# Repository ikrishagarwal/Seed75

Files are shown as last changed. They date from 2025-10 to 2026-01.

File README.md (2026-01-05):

# Seed75

A completely hand made 75% mechanical keyboard from PCB to case, even the firmware.

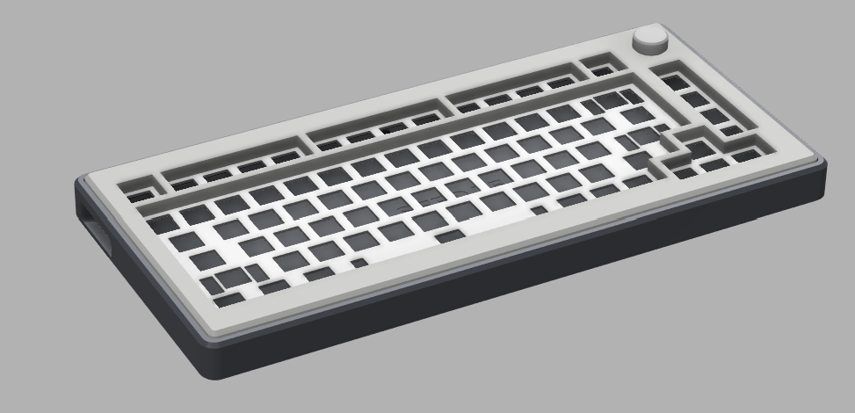
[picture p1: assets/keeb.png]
Seed75


## Features

- 75% Layout
- Hot Swappable Sockets
- Sleep Design
- Customizable Push Knob
- USB C Port
- Detachable Angle Elevation
- Sandwich Mount
- Wrist Rest

## Images

### PCB Schematics

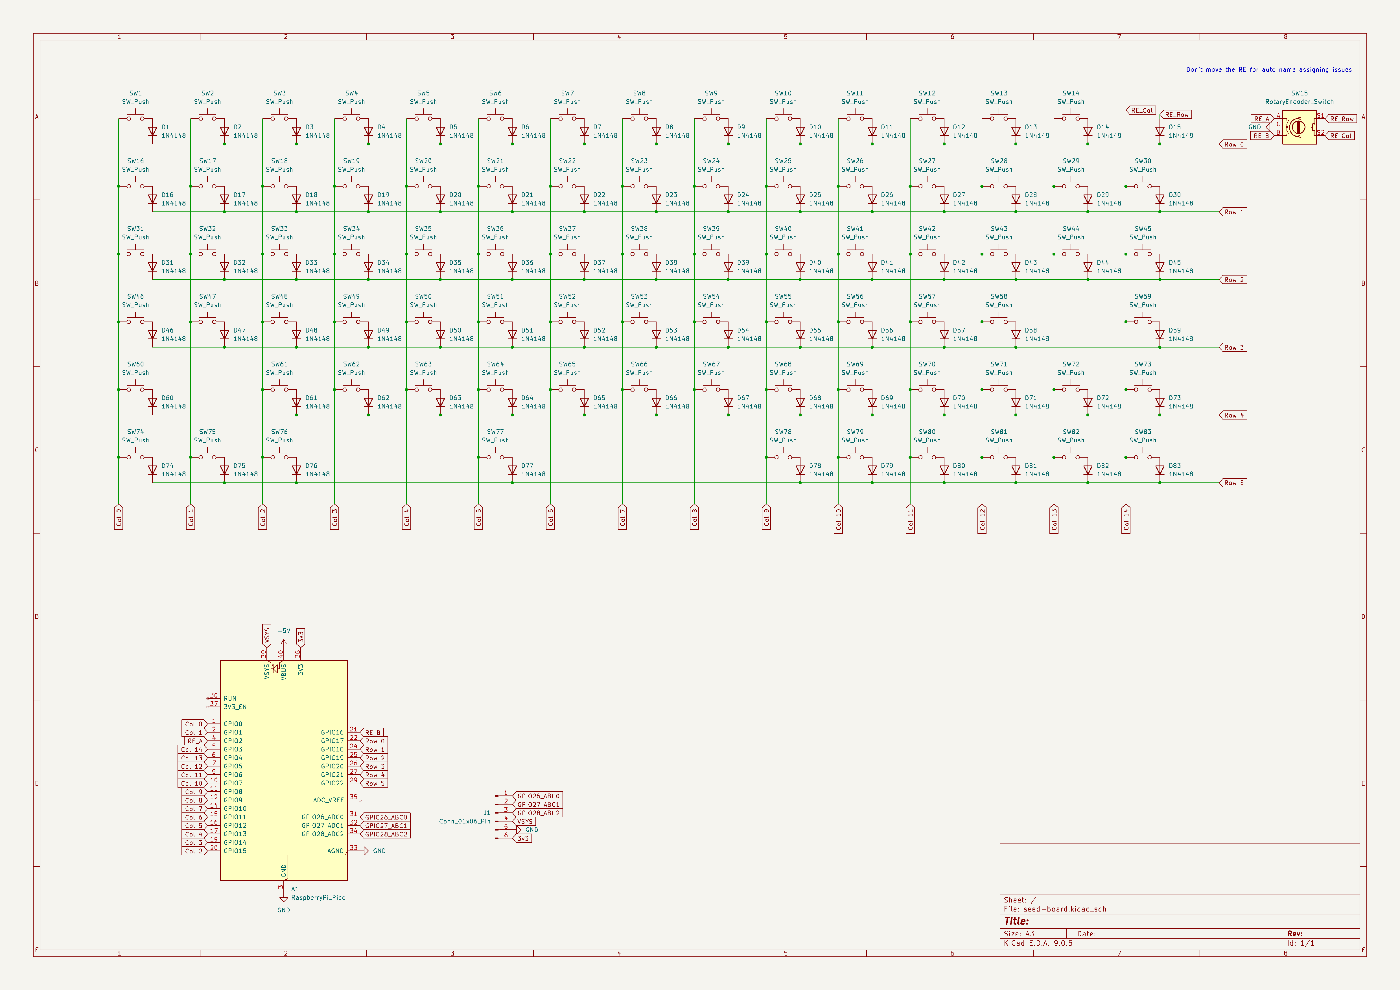
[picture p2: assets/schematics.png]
PCB Schematics


### PCB

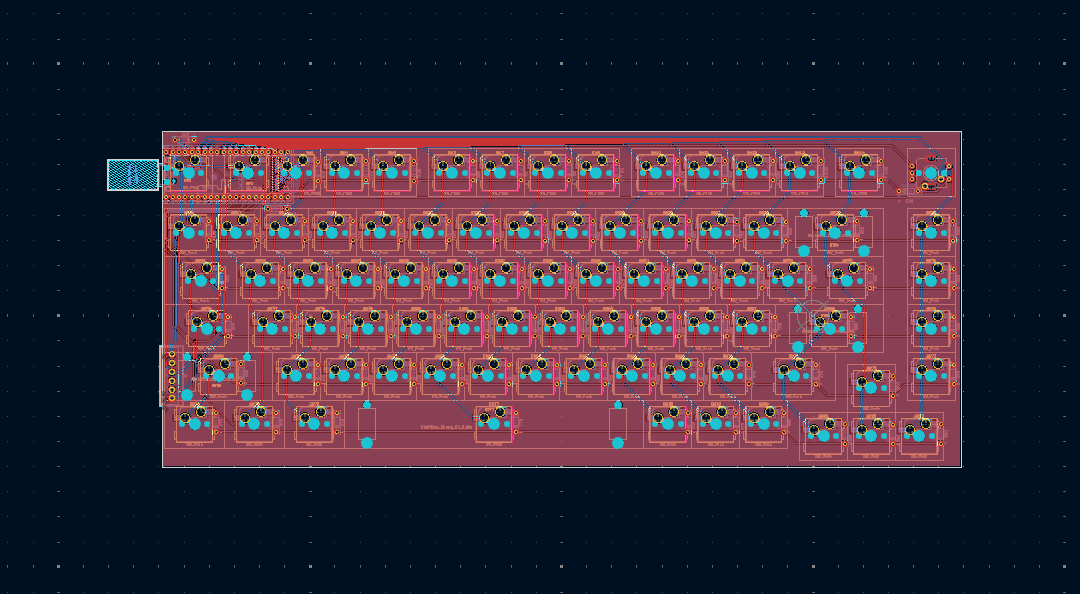
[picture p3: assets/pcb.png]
PCB


### PCB Front Layer

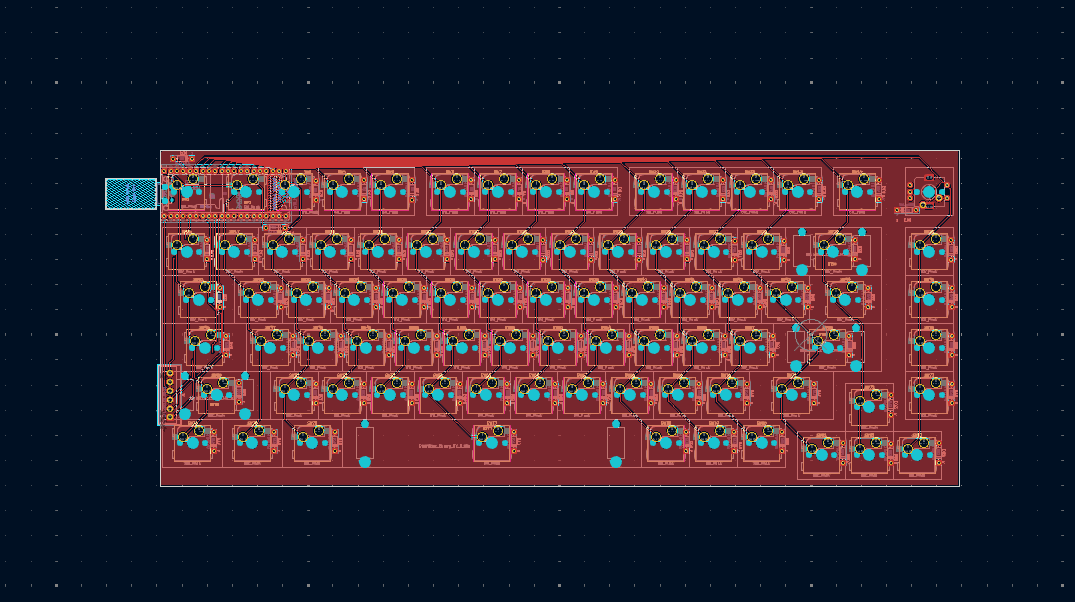
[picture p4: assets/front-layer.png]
PCB Front Layer


### PCB Back Layer

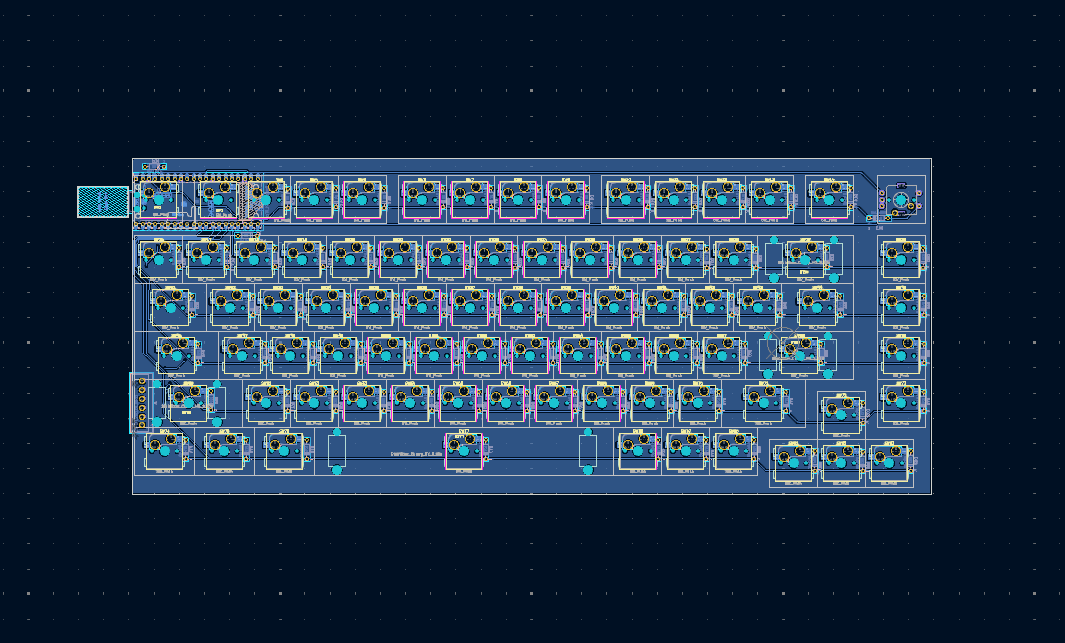
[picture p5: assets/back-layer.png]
PCB Back Layer


### PCB Rendered Front

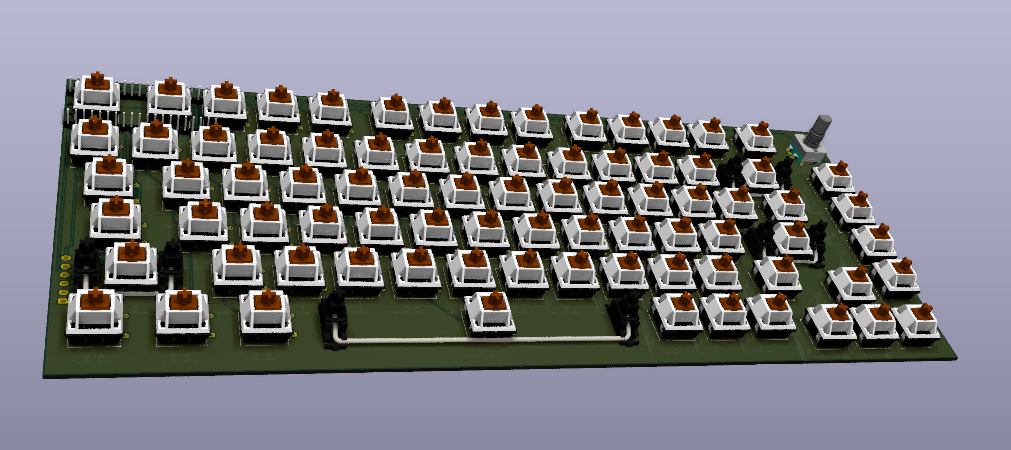
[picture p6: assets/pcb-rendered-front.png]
PCB Top


### PCB Rendered Back

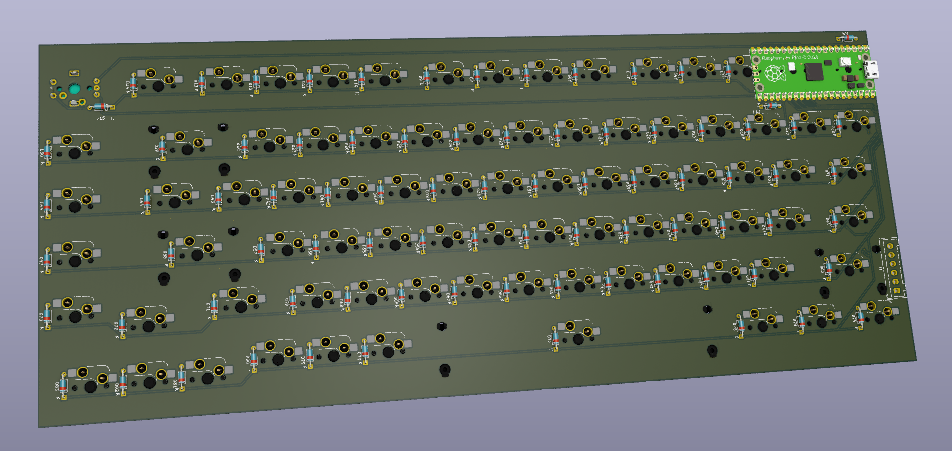
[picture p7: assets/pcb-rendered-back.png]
PCB Back


### Complete Case

Case

### Bottom Case

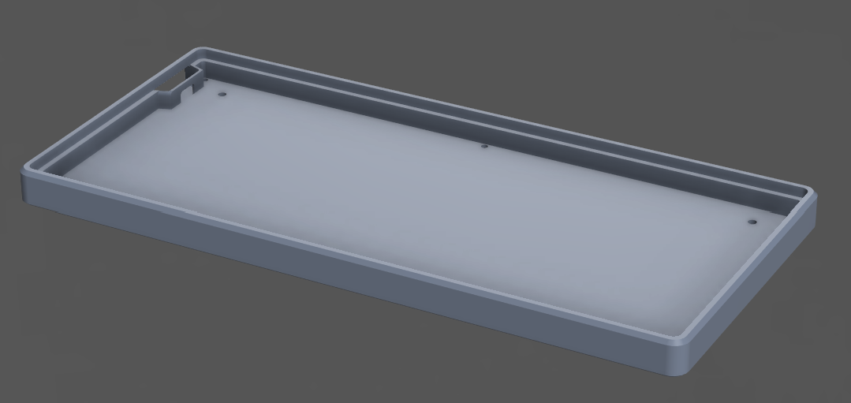
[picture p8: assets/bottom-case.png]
Bottom Case


### Top Case

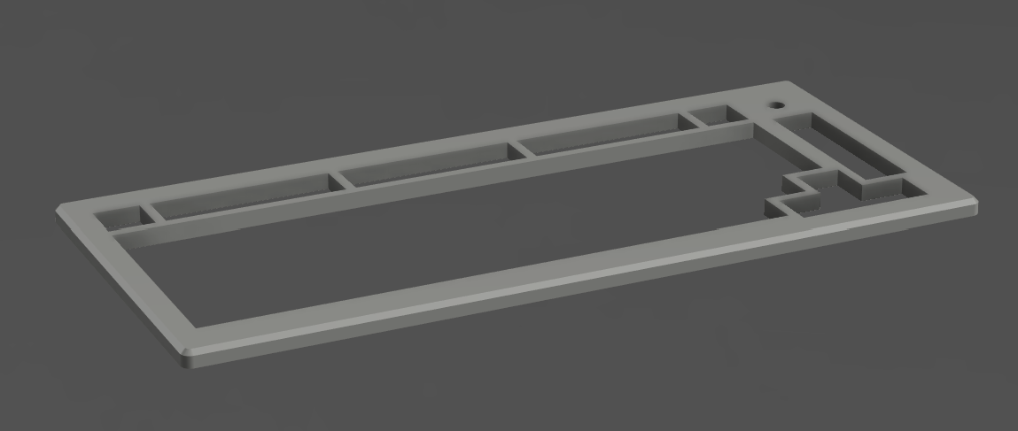
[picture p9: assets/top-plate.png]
Top Case


### Plate

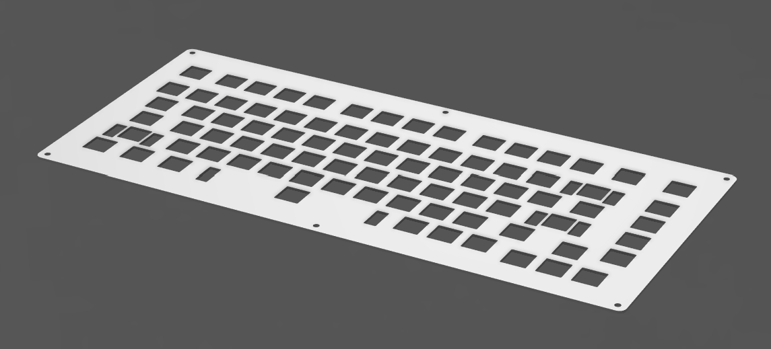
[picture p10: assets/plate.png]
Plate


### Elevator

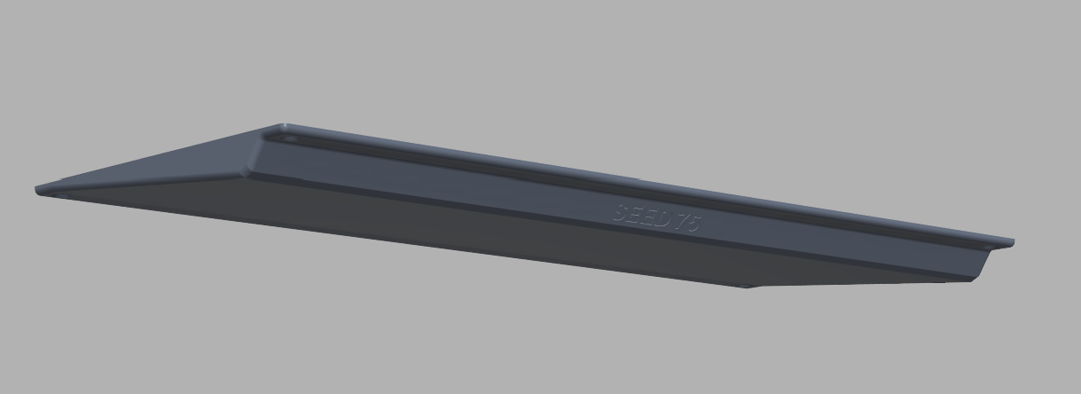
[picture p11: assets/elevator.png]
Elevator


### Wrist Rest

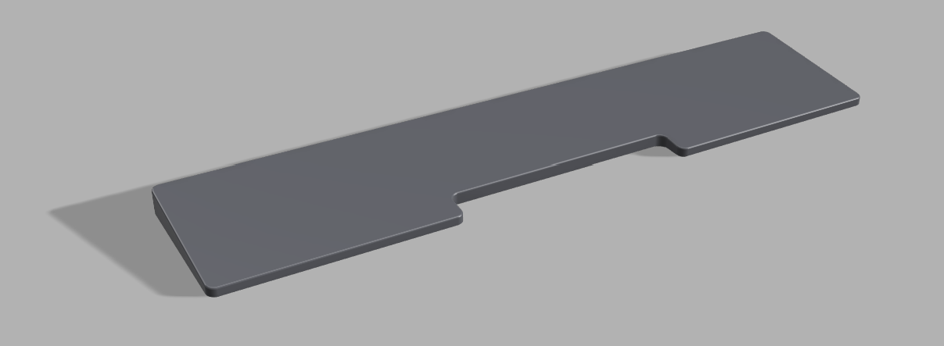
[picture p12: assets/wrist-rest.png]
Wrist Rest


### Knob

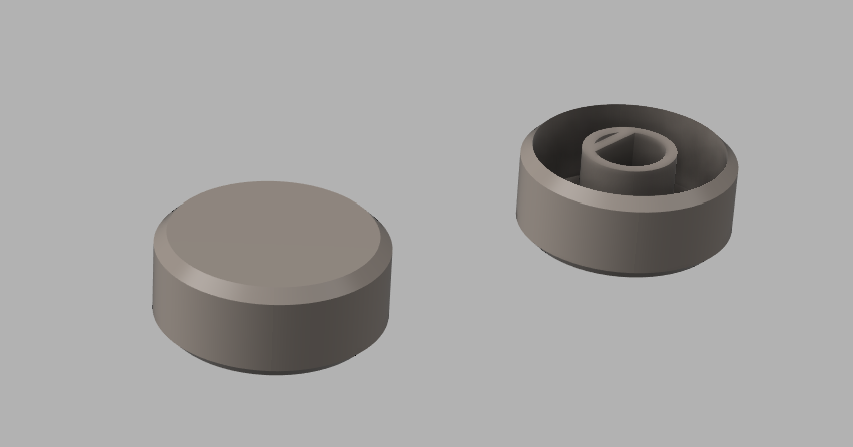
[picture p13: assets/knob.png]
Knob


### BOM

| Item | Quantity | Cost (USD)\* | Purchase Link |
| --- | --- | --- | --- |
| 1N4148 Diodes | 90 Pack  | 1.52 | https://stackskb.com/store/1n4148-through-hole-diode/ |
| Akko Bittersweet Switch | 90 Pack  | 33.40 | https://stackskb.com/store/akko-bittersweet-switch-pack-of-45/ |
| EC11 Rotary Encoder | 1 | 0.43 | https://www.flyrobo.in/ec11-rotary-encoder-half-shaft-handle-potentiometer-15mm |
| Orpheus Pico | 1 | | Hack Club |
| Gateron Hotswap Sockets | 90 Pack  | 10.00 | https://stackskb.com/store/gateron-hotswap-sockets/ |
| Durock v2 Stabilizers Set | 1 | 17.98 | https://stackskb.com/store/durock-clear-screw-in-stabilizers-v2/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 |
| Keycap Set | 1 | 22.21 | https://curiositycaps.in/products/camp-picnic-xvx-p-profile-dye-sub-doubleshot-combination-keycap |
| M3x20 Hex CSK Screws | 6x2 | 0.20 | https://omrook.com/ss-allen-csk-m3-x-20mm-dia-3mm-length-20mm-stainless-steel-ss202-allen-socket-countersunk-screws/ |
| M3x6 Hex CSK Screws | 4x2 | 0.05 | https://omrook.com/ss-allen-csk-m3-x-6mm-dia-3mm-length-6mm-stainless-steel-ss202-allen-socket-countersunk-screws/ |
| M3 X 3mm Brass Threaded Inserts | 10x2 | 0.83 | https://omrook.com/m3-x-4-brass-threaded-inserts-nut-50pc/ |
| Bottom Case, Top Case, Plate, Knob, Elevator, Wrist Rest | 1 | | (3D Printed) |
| PCB | 1 | 56.87 | https://www.pcbpower.com/ |

Cost is as of 01/01/2026

## Software Used

- KiCAD
- Fusion 360

## Author

[Krish](https://github.com/ikrishagarwal)

## License

This project is licensed under the [AGPL-3.0 License](LICENSE).

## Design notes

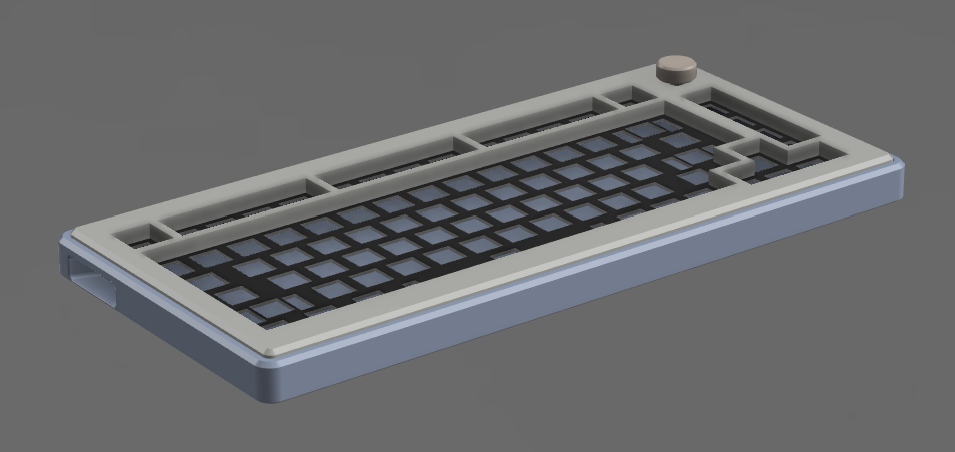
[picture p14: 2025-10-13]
assets/case.png

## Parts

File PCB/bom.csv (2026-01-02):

Designator | Footprint | Quantity | Value | LCSC Part #
A1 | Raspberry_Pi_Pico | 1 | RaspberryPi_Pico
D1, D10, D11, D12, D13, D14, D15, D16, D17, D18, D19, D2, D20, D21, D22, D23, D24, D25, D26, D27, D28, D29, D3, D30, D31, D32, D33, D34, D35, D36, D37, D38, D39, D4, D40, D41, D42, D43, D44, D45, D46, D47, D48, D49, D5, D50, D51, D52, D53, D54, D55, D56, D57, D58, D59, D6, D60, D61, D62, D63, D64, D65, D66, D67, D68, D69, D7, D70, D71, D72, D73, D74, D75, D76, D77, D78, D79, D8, D80, D81, D82, D83, D9 | D_DO-35_SOD27_P7.62mm_Horizontal | 83 | 1N4148
J1 | Wago_734-136_1x06_P3.50mm_Vertical | 1 | Conn_01x06_Pin
SW1, SW10, SW11, SW12, SW13, SW14, SW16, SW17, SW18, SW19, SW2, SW20, SW21, SW22, SW23, SW24, SW25, SW26, SW27, SW28, SW3, SW30, SW32, SW33, SW34, SW35, SW36, SW37, SW38, SW39, SW4, SW40, SW41, SW42, SW43, SW45, SW47, SW48, SW49, SW5, SW50, SW51, SW52, SW53, SW54, SW55, SW56, SW57, SW59, SW6, SW61, SW62, SW63, SW64, SW65, SW66, SW67, SW68, SW69, SW7, SW70, SW72, SW73, SW78, SW79, SW8, SW80, SW81, SW82, SW83, SW9 | SW_Hotswap_Kailh_MX_Plated_1.00u_With_Switch | 71 | SW_Push
SW15 | Encoder_EC11_MX_Combo | 1 | RotaryEncoder_Switch
SW29 | SW_Hotswap_Kailh_MX_Plated_2.00u_With_Switch | 1 | SW_Push
SW31, SW44 | SW_Hotswap_Kailh_MX_Plated_1.50u_With_Switch | 2 | SW_Push
SW46, SW71 | SW_Hotswap_Kailh_MX_Plated_1.75u_With_Switch | 2 | SW_Push
SW58, SW60 | SW_Hotswap_Kailh_MX_Plated_2.25u_With_Switch | 2 | SW_Push
SW74, SW75, SW76 | SW_Hotswap_Kailh_MX_Plated_1.25u_With_Switch | 3 | SW_Push
SW77 | SW_Hotswap_Kailh_MX_Plated_6.25u_With_Switch | 1 | SW_Push

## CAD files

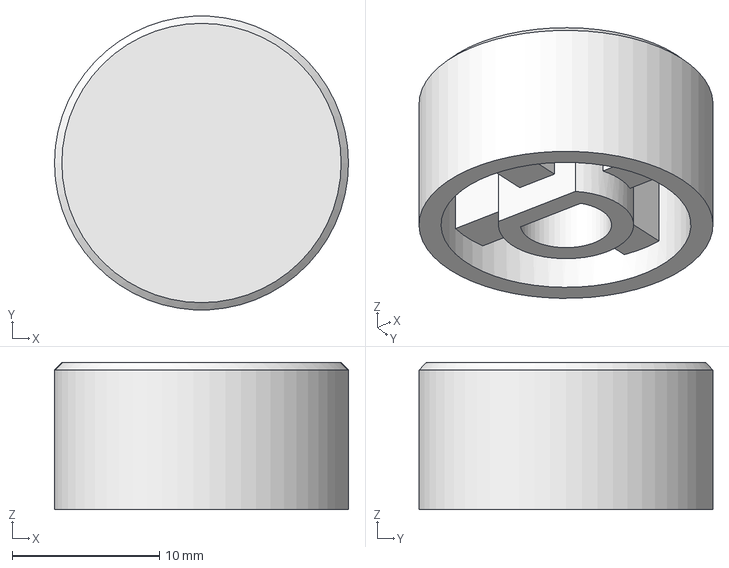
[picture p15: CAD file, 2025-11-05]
CAD/Knob.step
20.0 x 20.0 x 10.0 mm

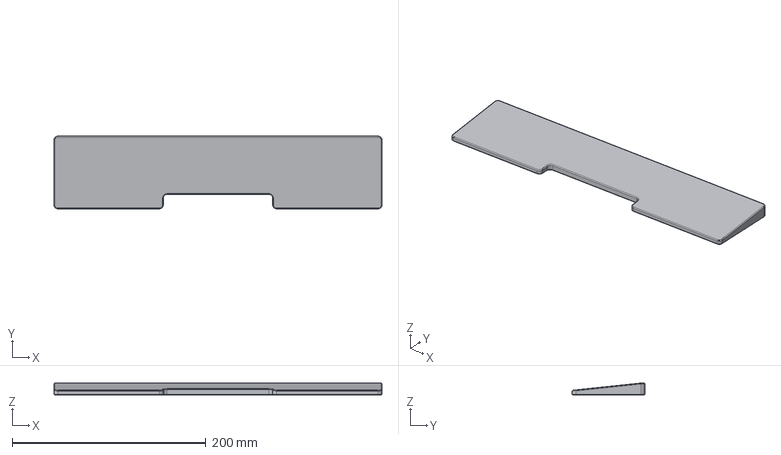
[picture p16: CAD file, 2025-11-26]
Production/WristRest.step
338.8 x 75.0 x 12.9 mm

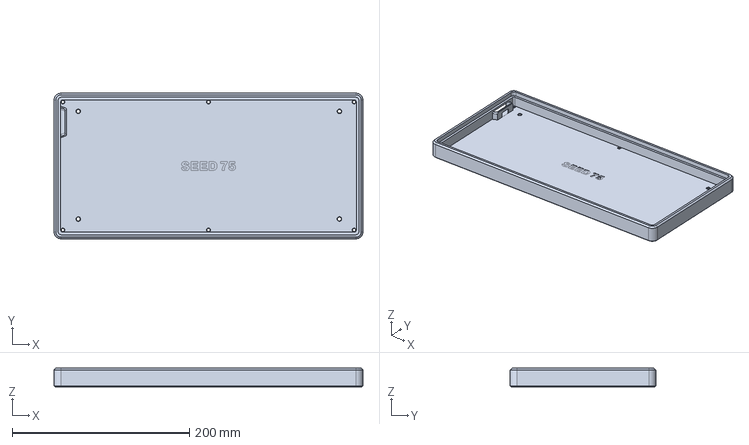
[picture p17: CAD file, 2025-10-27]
CAD/Bottom Case.step
348.8 x 164.5 x 21.0 mm

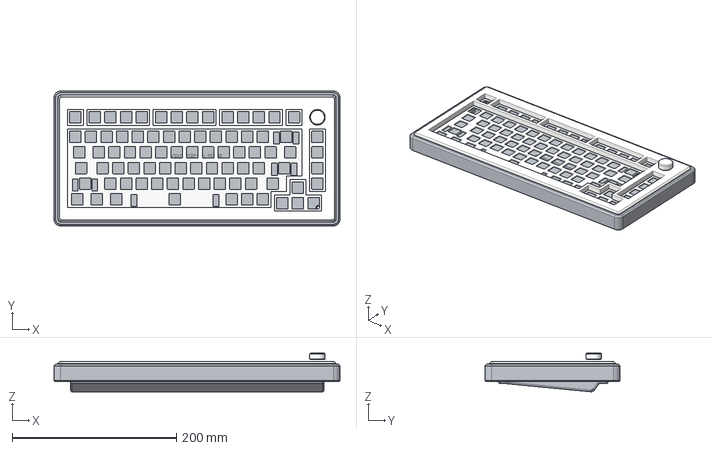
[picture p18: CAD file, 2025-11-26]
Production/Seed75.step
348.8 x 164.5 x 47.3 mm

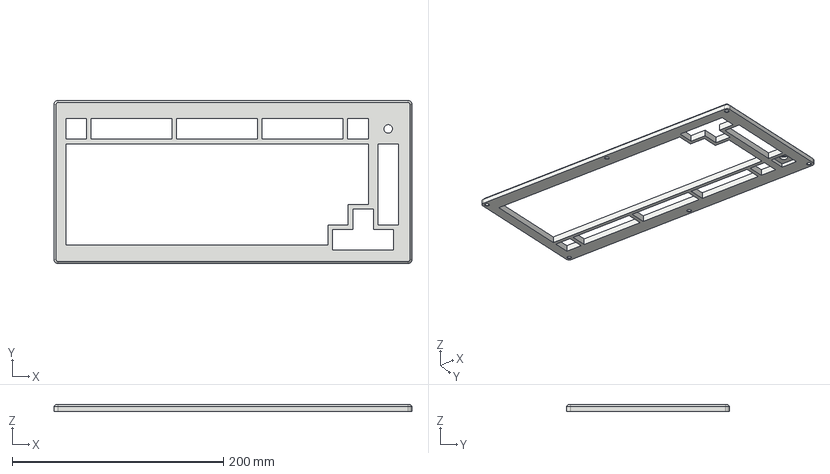
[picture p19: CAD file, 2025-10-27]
CAD/Top Case.step
338.8 x 154.5 x 7.00 mm

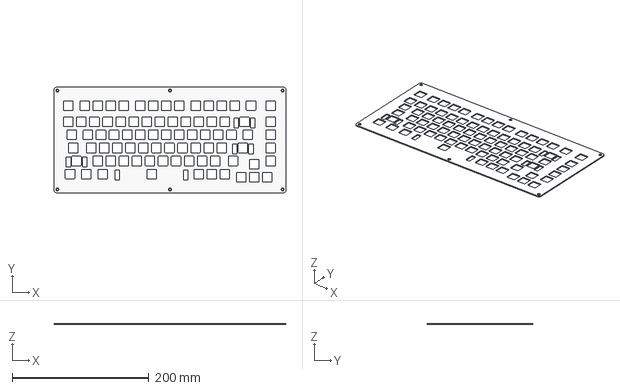
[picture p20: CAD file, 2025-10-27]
CAD/Plate.step
338.8 x 154.5 x 1.50 mm

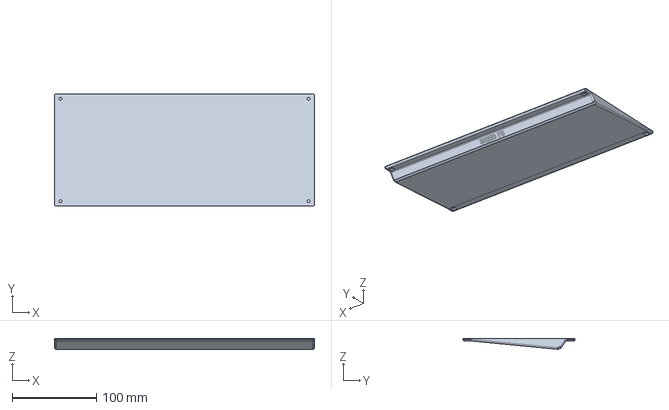
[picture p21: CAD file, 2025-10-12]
CAD/Stand.step
308.8 x 133.5 x 12.8 mm

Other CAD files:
CAD/Wrist Rest.step
CAD/Bottom Case.stl
CAD/Knob.stl
CAD/Plate.stl
CAD/Stand.stl
CAD/Top Case.stl
CAD/Wrist Rest.stl

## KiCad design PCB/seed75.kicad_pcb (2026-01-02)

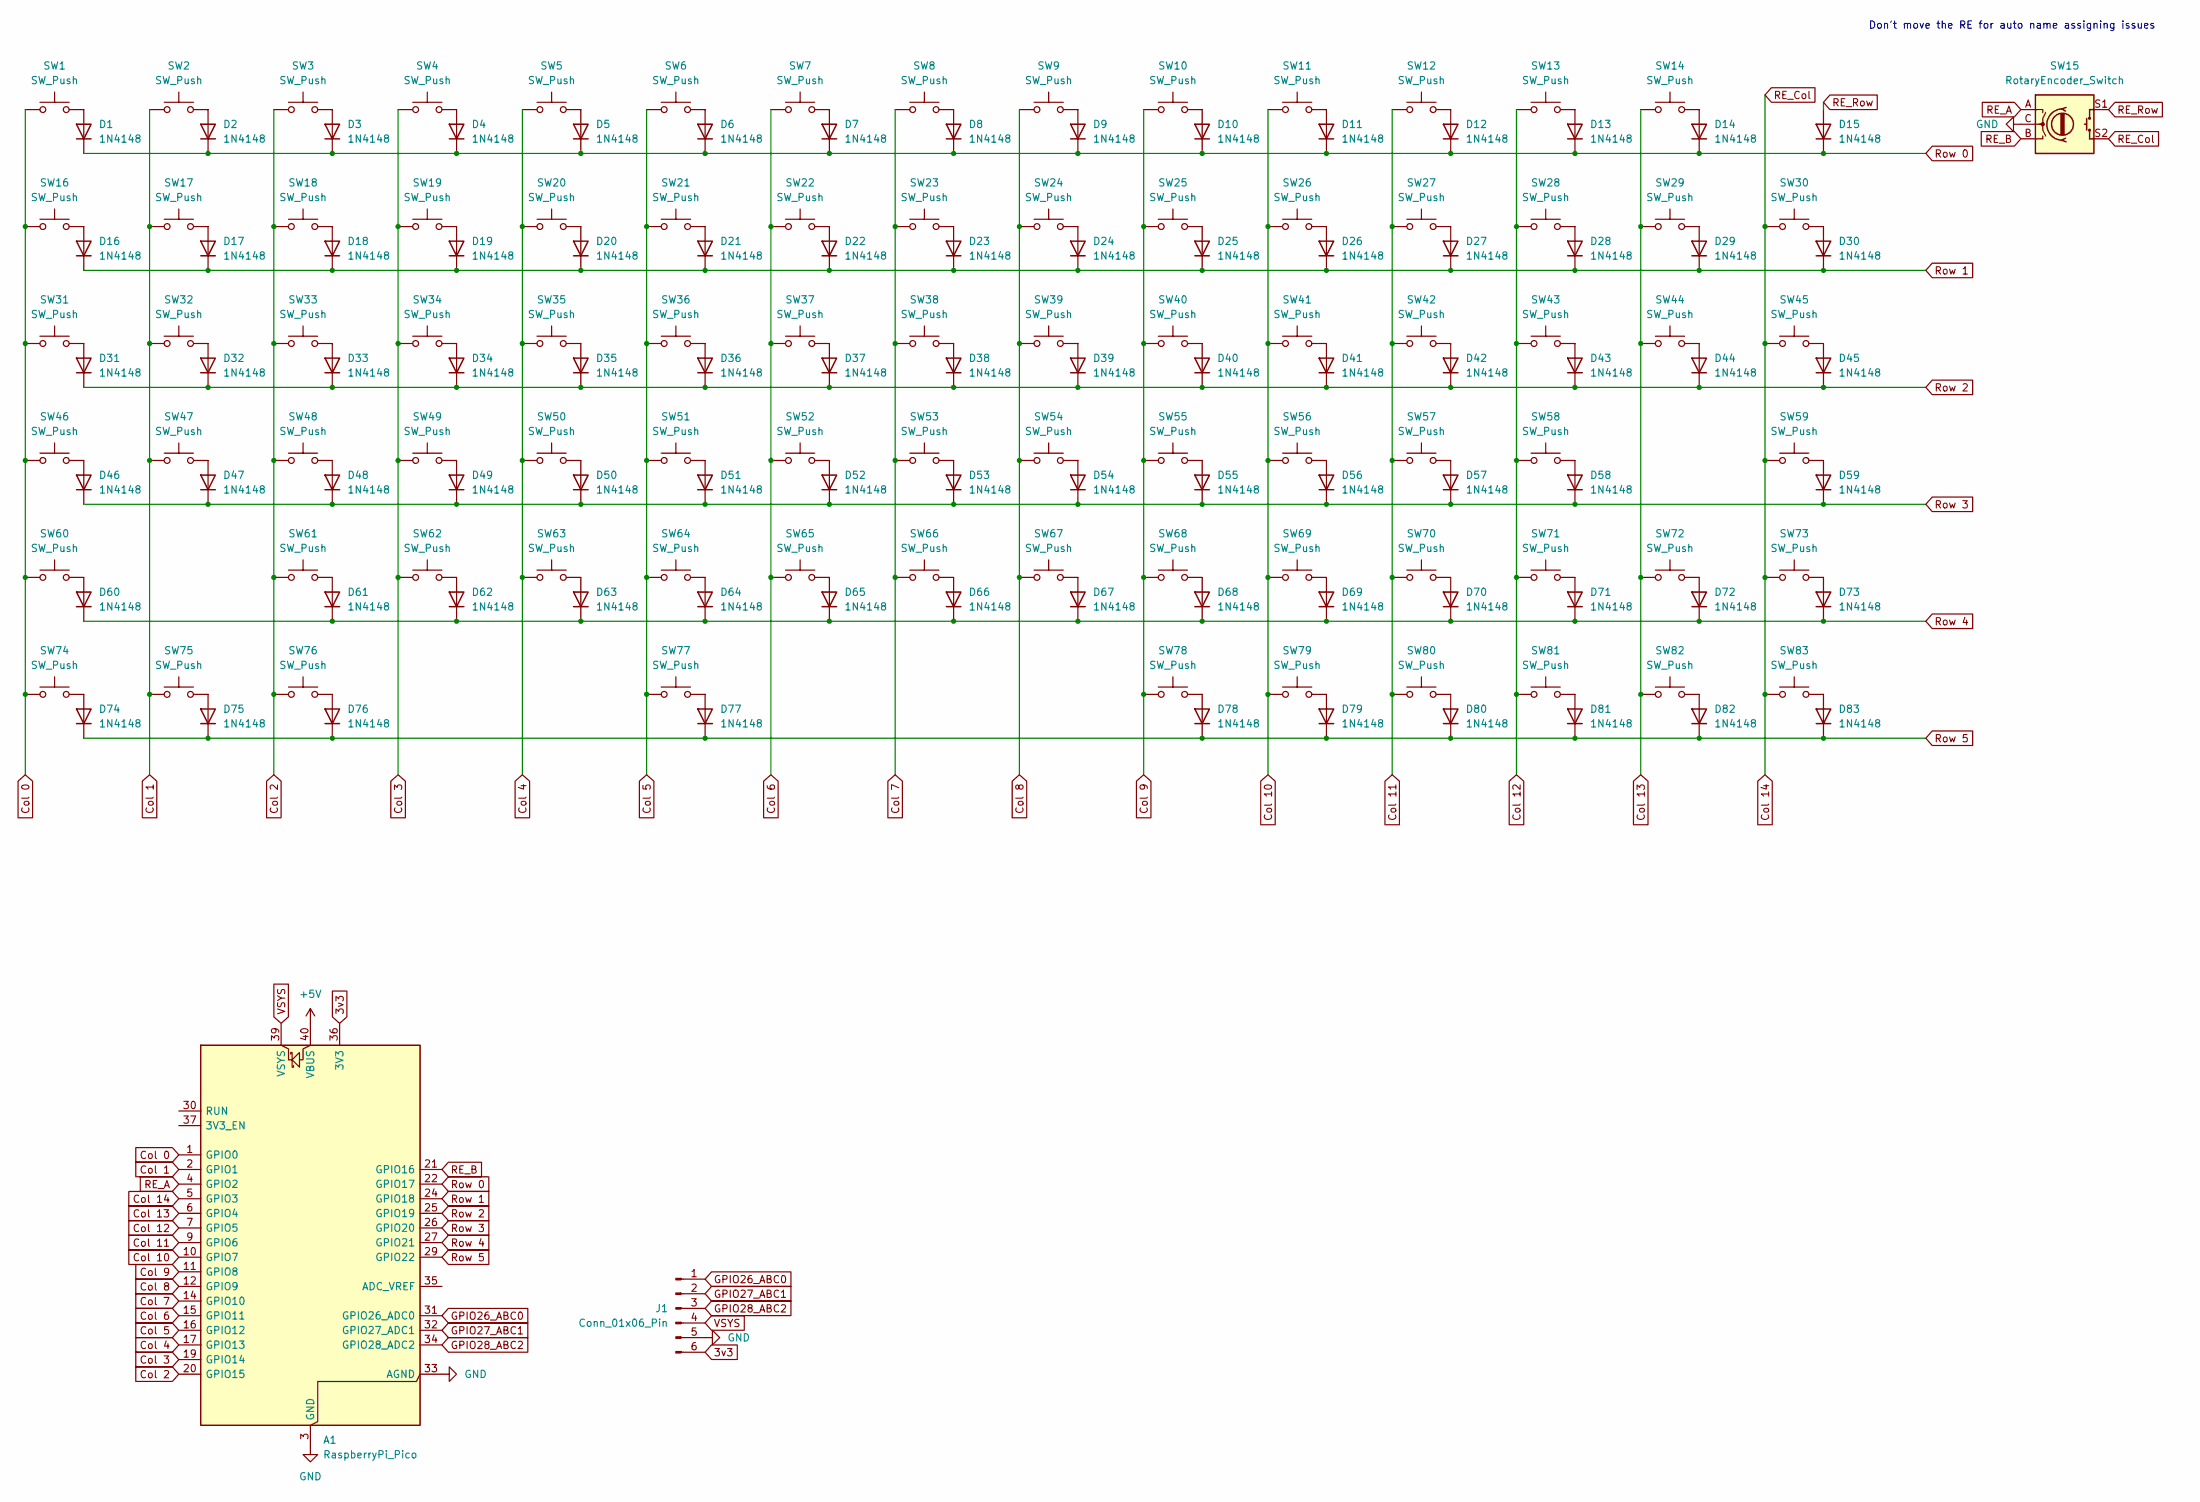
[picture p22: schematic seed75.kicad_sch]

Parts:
A1: RaspberryPi_Pico; Raspberry_Pi_Pico
D1, D2, D3, D4, D5, D6, D7, D8, D9, D10, D11, D12, D13, D14, D15, D16, D17, D18, D19, D20, D21, D22, D23, D24, D25, D26, D27, D28, D29, D30, D31, D32, D33, D34, D35, D36, D37, D38, D39, D40, D41, D42, D43, D44, D45, D46, D47, D48, D49, D50, D51, D52, D53, D54, D55, D56, D57, D58, D59, D60, D61, D62, D63, D64, D65, D66, D67, D68, D69, D70, D71, D72, D73, D74, D75, D76, D77, D78, D79, D80, D81, D82, D83: 1N4148; D_DO-35_SOD27_P7.62mm_Horizontal
J1: Conn_01x06_Pin; Wago_734-136_1x06_P3.50mm_Vertical
SW1, SW2, SW3, SW4, SW5, SW6, SW7, SW8, SW9, SW10, SW11, SW12, SW13, SW14, SW16, SW17, SW18, SW19, SW20, SW21, SW22, SW23, SW24, SW25, SW26, SW27, SW28, SW30, SW32, SW33, SW34, SW35, SW36, SW37, SW38, SW39, SW40, SW41, SW42, SW43, SW45, SW47, SW48, SW49, SW50, SW51, SW52, SW53, SW54, SW55, SW56, SW57, SW59, SW61, SW62, SW63, SW64, SW65, SW66, SW67, SW68, SW69, SW70, SW72, SW73, SW78, SW79, SW80, SW81, SW82, SW83: SW_Push; SW_Hotswap_Kailh_MX_Plated_1.00u_With_Switch
SW15: RotaryEncoder_Switch; Encoder_EC11_MX_Combo
SW29: SW_Push; SW_Hotswap_Kailh_MX_Plated_2.00u_With_Switch
SW31, SW44: SW_Push; SW_Hotswap_Kailh_MX_Plated_1.50u_With_Switch
SW46, SW71: SW_Push; SW_Hotswap_Kailh_MX_Plated_1.75u_With_Switch
SW58, SW60: SW_Push; SW_Hotswap_Kailh_MX_Plated_2.25u_With_Switch
SW74, SW75, SW76: SW_Push; SW_Hotswap_Kailh_MX_Plated_1.25u_With_Switch
SW77: SW_Push; SW_Hotswap_Kailh_MX_Plated_6.25u_With_Switch

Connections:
3v3: A1.36 (3V3), J1.6
+5V: A1.40 (VBUS)
Col 0: A1.1 (GPIO0), SW1.1, SW16.1, SW31.1, SW46.1, SW60.1, SW74.1
Col 1: A1.2 (GPIO1), SW2.1, SW17.1, SW32.1, SW47.1, SW75.1
Col 2: A1.20 (GPIO15), SW3.1, SW18.1, SW33.1, SW48.1, SW61.1, SW76.1
Col 3: A1.19 (GPIO14), SW4.1, SW19.1, SW34.1, SW49.1, SW62.1
Col 4: A1.17 (GPIO13), SW5.1, SW20.1, SW35.1, SW50.1, SW63.1
Col 5: A1.16 (GPIO12), SW6.1, SW21.1, SW36.1, SW51.1, SW64.1, SW77.1
Col 6: A1.15 (GPIO11), SW7.1, SW22.1, SW37.1, SW52.1, SW65.1
Col 7: A1.14 (GPIO10), SW8.1, SW23.1, SW38.1, SW53.1, SW66.1
Col 8: A1.12 (GPIO9), SW9.1, SW24.1, SW39.1, SW54.1, SW67.1
Col 9: A1.11 (GPIO8), SW10.1, SW25.1, SW40.1, SW55.1, SW68.1, SW78.1
Col 10: A1.10 (GPIO7), SW11.1, SW26.1, SW41.1, SW56.1, SW69.1, SW79.1
Col 11: A1.9 (GPIO6), SW12.1, SW27.1, SW42.1, SW57.1, SW70.1, SW80.1
Col 12: A1.7 (GPIO5), SW13.1, SW28.1, SW43.1, SW58.1, SW71.1, SW81.1
Col 13: A1.6 (GPIO4), SW14.1, SW29.1, SW44.1, SW72.1, SW82.1
Col 14: A1.5 (GPIO3), SW15.S2, SW30.1, SW45.1, SW59.1, SW73.1, SW83.1
GND: A1.3 (GND), A1.8 (GND), A1.13 (GND), A1.18 (GND), A1.23 (GND), A1.28 (GND), A1.33 (AGND), A1.38 (GND), J1.5, SW15.C
GPIO26_ABC0: A1.31 (GPIO26_ADC0), J1.1
GPIO27_ABC1: A1.32 (GPIO27_ADC1), J1.2
GPIO28_ABC2: A1.34 (GPIO28_ADC2), J1.3
unnamed: D1.2 (A), SW1.2
unnamed: D2.2 (A), SW2.2
unnamed: D3.2 (A), SW3.2
unnamed: D4.2 (A), SW4.2
unnamed: D5.2 (A), SW5.2
unnamed: D6.2 (A), SW6.2
unnamed: D7.2 (A), SW7.2
unnamed: D8.2 (A), SW8.2
unnamed: D9.2 (A), SW9.2
unnamed: D10.2 (A), SW10.2
unnamed: D11.2 (A), SW11.2
unnamed: D12.2 (A), SW12.2
unnamed: D13.2 (A), SW13.2
unnamed: D14.2 (A), SW14.2
unnamed: D16.2 (A), SW16.2
unnamed: D17.2 (A), SW17.2
unnamed: D18.2 (A), SW18.2
unnamed: D19.2 (A), SW19.2
unnamed: D20.2 (A), SW20.2
unnamed: D21.2 (A), SW21.2
unnamed: D22.2 (A), SW22.2
unnamed: D23.2 (A), SW23.2
unnamed: D24.2 (A), SW24.2
unnamed: D25.2 (A), SW25.2
unnamed: D26.2 (A), SW26.2
unnamed: D27.2 (A), SW27.2
unnamed: D28.2 (A), SW28.2
unnamed: D29.2 (A), SW29.2
unnamed: D30.2 (A), SW30.2
unnamed: D31.2 (A), SW31.2
unnamed: D32.2 (A), SW32.2
unnamed: D33.2 (A), SW33.2
unnamed: D34.2 (A), SW34.2
unnamed: D35.2 (A), SW35.2
unnamed: D36.2 (A), SW36.2
unnamed: D37.2 (A), SW37.2
unnamed: D38.2 (A), SW38.2
unnamed: D39.2 (A), SW39.2
unnamed: D40.2 (A), SW40.2
unnamed: D41.2 (A), SW41.2
unnamed: D42.2 (A), SW42.2
unnamed: D43.2 (A), SW43.2
unnamed: D44.2 (A), SW44.2
unnamed: D45.2 (A), SW45.2
unnamed: D46.2 (A), SW46.2
unnamed: D47.2 (A), SW47.2
unnamed: D48.2 (A), SW48.2
unnamed: D49.2 (A), SW49.2
unnamed: D50.2 (A), SW50.2
unnamed: D51.2 (A), SW51.2
unnamed: D52.2 (A), SW52.2
unnamed: D53.2 (A), SW53.2
unnamed: D54.2 (A), SW54.2
unnamed: D55.2 (A), SW55.2
unnamed: D56.2 (A), SW56.2
unnamed: D57.2 (A), SW57.2
unnamed: D58.2 (A), SW58.2
unnamed: D59.2 (A), SW59.2
unnamed: D60.2 (A), SW60.2
unnamed: D61.2 (A), SW61.2
unnamed: D62.2 (A), SW62.2
unnamed: D63.2 (A), SW63.2
unnamed: D64.2 (A), SW64.2
unnamed: D65.2 (A), SW65.2
unnamed: D66.2 (A), SW66.2
unnamed: D67.2 (A), SW67.2
unnamed: D68.2 (A), SW68.2
unnamed: D69.2 (A), SW69.2
unnamed: D70.2 (A), SW70.2
unnamed: D71.2 (A), SW71.2
unnamed: D72.2 (A), SW72.2
unnamed: D73.2 (A), SW73.2
unnamed: D74.2 (A), SW74.2
unnamed: D75.2 (A), SW75.2
unnamed: D76.2 (A), SW76.2
unnamed: D77.2 (A), SW77.2
unnamed: D78.2 (A), SW78.2
unnamed: D79.2 (A), SW79.2
unnamed: D80.2 (A), SW80.2
unnamed: D81.2 (A), SW81.2
unnamed: D82.2 (A), SW82.2
unnamed: D83.2 (A), SW83.2
RE_A: A1.4 (GPIO2), SW15.A
RE_B: A1.21 (GPIO16), SW15.B
RE_Row: D15.2 (A), SW15.S1
Row 0: A1.22 (GPIO17), D1.1 (K), D2.1 (K), D3.1 (K), D4.1 (K), D5.1 (K), D6.1 (K), D7.1 (K), D8.1 (K), D9.1 (K), D10.1 (K), D11.1 (K), D12.1 (K), D13.1 (K), D14.1 (K), D15.1 (K)
Row 1: A1.24 (GPIO18), D16.1 (K), D17.1 (K), D18.1 (K), D19.1 (K), D20.1 (K), D21.1 (K), D22.1 (K), D23.1 (K), D24.1 (K), D25.1 (K), D26.1 (K), D27.1 (K), D28.1 (K), D29.1 (K), D30.1 (K)
Row 2: A1.25 (GPIO19), D31.1 (K), D32.1 (K), D33.1 (K), D34.1 (K), D35.1 (K), D36.1 (K), D37.1 (K), D38.1 (K), D39.1 (K), D40.1 (K), D41.1 (K), D42.1 (K), D43.1 (K), D44.1 (K), D45.1 (K)
Row 3: A1.26 (GPIO20), D46.1 (K), D47.1 (K), D48.1 (K), D49.1 (K), D50.1 (K), D51.1 (K), D52.1 (K), D53.1 (K), D54.1 (K), D55.1 (K), D56.1 (K), D57.1 (K), D58.1 (K), D59.1 (K)
Row 4: A1.27 (GPIO21), D60.1 (K), D61.1 (K), D62.1 (K), D63.1 (K), D64.1 (K), D65.1 (K), D66.1 (K), D67.1 (K), D68.1 (K), D69.1 (K), D70.1 (K), D71.1 (K), D72.1 (K), D73.1 (K)
Row 5: A1.29 (GPIO22), D74.1 (K), D75.1 (K), D76.1 (K), D77.1 (K), D78.1 (K), D79.1 (K), D80.1 (K), D81.1 (K), D82.1 (K), D83.1 (K)
VSYS: A1.39 (VSYS), J1.4

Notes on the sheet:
Don't move the RE for auto name assigning issues

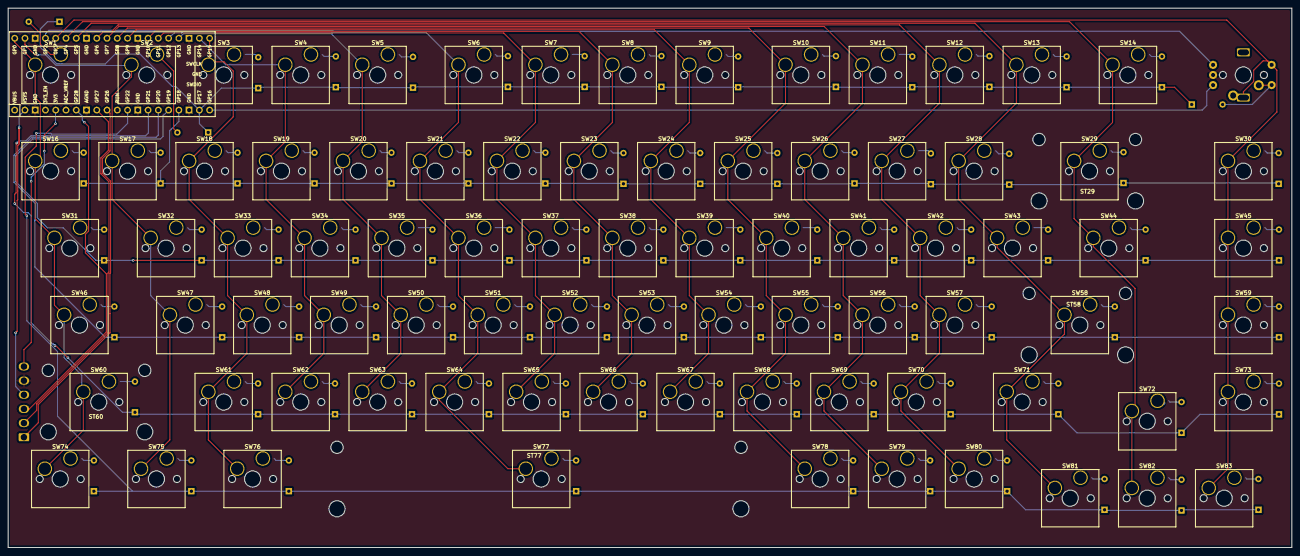
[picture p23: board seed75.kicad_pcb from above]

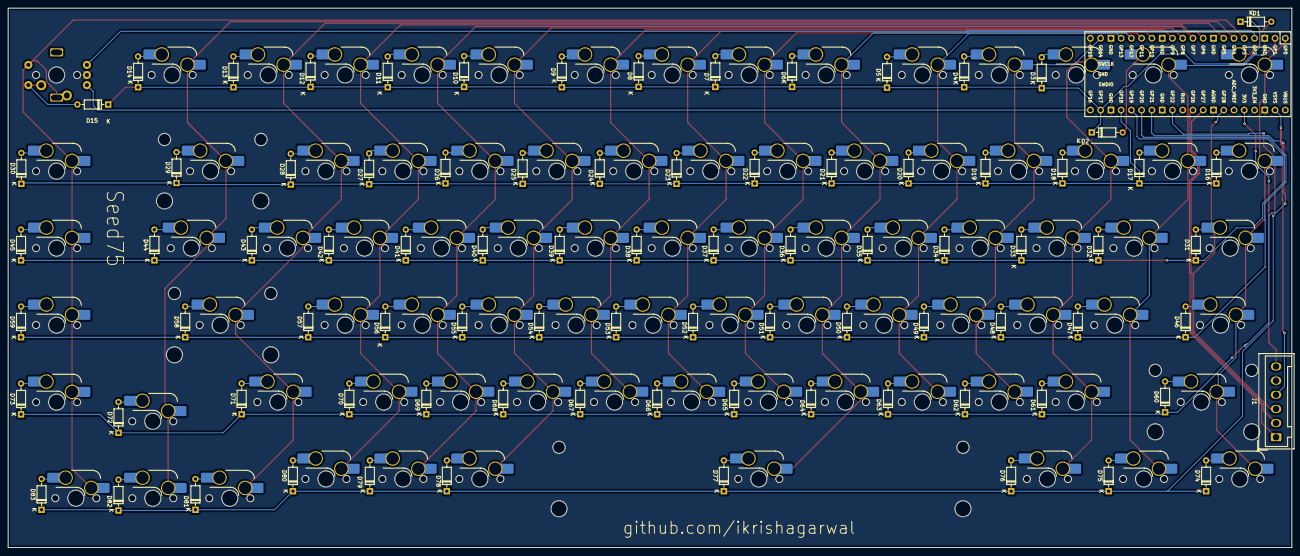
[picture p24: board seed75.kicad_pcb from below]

Board: 2 copper layers, 317.8 x 133.5 mm, 172 parts (85 on the bottom side), 112 nets.

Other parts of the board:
ST29, ST58, ST60: Stabilizer_Cherry_MX_2.00u
ST77: Stabilizer_Cherry_MX_6.25u

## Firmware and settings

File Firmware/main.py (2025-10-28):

import board
import time
from kmk.kmk_keyboard import KMKKeyboard
from kmk.scanners.keypad import MatrixScanner
from kmk.keys import KC
from kmk.modules.rotary_encoder import RotaryEncoderHandler

keyboard = KMKKeyboard()

keyboard.matrix = MatrixScanner(
    column_pins=[board.GP0, board.GP1, board.GP15, board.GP14, board.GP13, board.GP12, board.GP11,
                 board.GP10, board.GP9, board.GP8, board.GP7, board.GP6, board.GP5, board.GP4, board.GP3],
    row_pins=[board.GP17, board.GP18, board.GP19,
              board.GP20, board.GP21, board.GP22],
    value_when_pressed=False,
)

# Define Keymap (needs fixes)
keyboard.keymap = [
    [
        # Row 1
        KC.ESC, KC.F1, KC.F2, KC.F3, KC.F4, KC.F5, KC.F6, KC.F7, KC.F8, KC.F9, KC.F10, KC.F11, KC.F12, KC.PSCR,
        # Row 2
        KC.GRV, KC.N1, KC.N2, KC.N3, KC.N4, KC.N5, KC.N6, KC.N7, KC.N8, KC.N9, KC.N0, KC.MINS, KC.EQL, KC.BSPC,
        # Row 3
        KC.TAB, KC.Q, KC.W, KC.E, KC.R, KC.T, KC.Y, KC.U, KC.I, KC.O, KC.P, KC.LBRC, KC.RBRC, KC.BSLS,
        # Row 4
        KC.CAPS, KC.A, KC.S, KC.D, KC.F, KC.G, KC.H, KC.J, KC.L, KC.SCLN, KC.QUOT, KC.ENT, KC.DEL, KC.NO,
        # Row 5
        KC.LSFT, KC.Z, KC.X, KC.C, KC.V, KC.B, KC.N, KC.M, KC.COMM, KC.DOT, KC.SLSH, KC.RSFT, KC.UP, KC.END,
        # Row 6
        KC.LCTL, KC.LGUI, KC.LALT, KC.NO, KC.NO, KC.SPC, KC.RALT, KC.RGUI, KC.APP, KC.RCTL, KC.LEFT, KC.DOWN, KC.RGHT, KC.PGDN,
        # Row 7
        KC.NO, KC.NO, KC.NO, KC.NO, KC.NO, KC.NO, KC.NO, KC.NO, KC.NO, KC.SLCK, KC.PAUS, KC.INS, KC.HOME, KC.PGUP,
    ],
]

encoder = RotaryEncoderHandler(pin_a=board.GP2, pin_b=board.GP16)
encoder.rotation_cw = KC.VOLU  # Volume Up
encoder.rotation_ccw = KC.VOLD  # Volume Down
keyboard.modules.append(encoder)

if __name__ == '__main__':
  keyboard.go()

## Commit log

2025-10-12 feat: adds the case and pcb
    [Bottom Case.step, Bottom Case.stl, Knob.step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]
2025-10-13 feat: completes readme
    [Wrist Rest.step, Wrist Rest.stl, bom.csv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]
2025-10-27 fix: case design issues
    [Bottom Case.step, Bottom Case.stl, Plate.step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]
2025-10-28 fix: BOM list
2025-11-05 feat: updated PCB files
    [bom.csv, designators.csv, positions.csv]
2025-11-05 docs: updated the BOM list
    [BOM.csv]
2025-11-05 feat: updated images and knob
    [Knob.step, Knob.stl]
2025-11-26 feat: adds production folder
    [Seed75.step, WristRest.step]
2026-01-01 feat: updated BOM
    [BOM.csv]
2026-01-01 fix: csv issues
    [BOM.csv]
2026-01-02 feat: fixed to pcb
    [bom.csv, positions.csv, seed75.kicad_pcb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]
2026-01-02 fix: pcb changes
    [seed75.kicad_pcb]
2026-01-05 chore: changed the provider for screws
    [BOM.csv]
